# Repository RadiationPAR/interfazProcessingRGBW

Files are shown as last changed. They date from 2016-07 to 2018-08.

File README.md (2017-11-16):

# PowerPAR-Led DELMA
---
La formulación de un problema es a menudo más esencial que su solución, que puede ser meramente una materia de destreza experimental o matemática. "La especificación del problema a investigar implica que se ha comprendido plenamente el
tema de la investigación, hasta el punto de poder determinar exactamente los interrogantes principales que plantea y a cuya resolución se debe orientar la investigación." Einstein

## SISTEMA DE MEDICIÓN Y MONITOREO PARA EL ESTUDIO DEL EFECTO DE LA RADIACIÓN PAR EN LAS PLANTAS

Esta investigación discrimina la información científica y tecnológica experimental a la fecha sobre la Radiación Fotosintéticamente Activa (radiación integrada del rango de longitudes de onda que son capaces de producir actividad fotosintética en las plantas y otros organismos fotosintéticos como microalgas y bacterias).

Investigadores de todo el planeta exponen en sus artículos que los vegetales necesitan porciones de luz desde los 400nm hasta los 700 nm; conocer sus umbrales luminicos permitirá conseguir cosechas de gran producción y alta calidad; llevar un historial de datos sobre el efecto de la longitud de onda según las horas del día y los estadios de crecimiento de la planta permitirá a futuro disponer de hojas de datos para realizar agricultura de precisión en su parametro luminico. 

A continuación se plantea el desarrollo de un mecanismo de observación para la respuesta fisiológica del dosel vegetal (en especial de la fotosíntesis), a partir del diseño de un sistema de iluminación artificial basado en un estudio previo de sistemas de iluminación y la actual migración a sistemas de iluminación con tecnología LED y OLED cuyo espectro de radiación esta dado en una banda especifica lo que proporciona un menor gasto de potencia, y facilita irradiar la planta con la parte del espectro especifico que ella necesita según su estadio: germinación, vegetación y floración. 

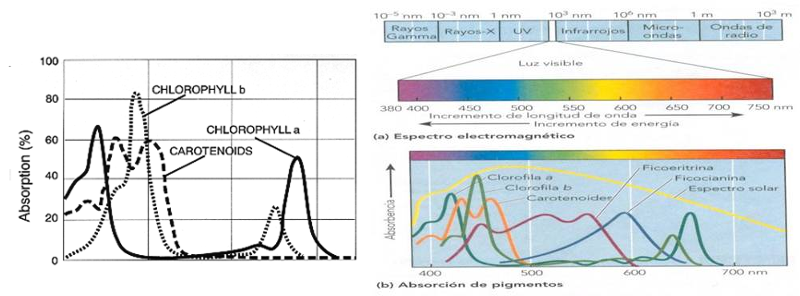
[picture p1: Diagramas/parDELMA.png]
RadiacionPAR
 

Fabricantes de todo el mundo, ofrecen al mercado diversas lamparas de iluminación y en algunos casos se diseñan enormes arreglos de leds con iluminación fija o invariable garantizando solo su uso para determinado tipo de plantas (C3, C4, CAM) - plantas presentes en la industria hortícola de mayor producción. Los investigadores de diversas tesis de Maestría y Doctorado no realizan un proceso fiable para llevar la trazabilidad de sus datos pero nos ilustran sobre el metodo científico iterado para obtener mejoras en el proceso de crecimiento y floración de diversas genéticas de plantas.  

Esta investigación contempla el desarrollo de un prototipo que permite al usuario manejar: la composición de color (longitud de onda) a irradiar y su potencia a traves de una interfaz de fácil manejo que almacena datos de manera centralizada como lo son: composición RGB (0-255), composición CMY (0 - 255), Matiz (0 - 360), saturación (0.0 - 1.0), luminancia (0.0 - 1.0), posición XYZ del color, longitud de onda y frecuencia.   

# Materiales
---  
## Microcontrolador Tiva C Series  
Se decide implementar este microcontrolador por su fama en internet acerca de la adquisición, procesamiento y almacenamiento de datos; ademas se sirve de una librería para la compresión de algoritmos matemáticos, lo cual resulta bastante interesante y acorde para las conversiones de los diferentes modelos matemáticos de los espacios del color.
Energia LaunchPad MSP-EXP430G2 LaunchPad 

## Sensor TCS3220 y Led RGB 100W
Se opta por implementar el sensor TCS3220 por su resolución y economía; basicamente entrega una señal cuadrada con ancho de pulso variable de acuerdo a la presencia de una fuente de luz. Se caracteriza el comportamiento del sensor con la hoja de datos del fabricante y datos de pruebas en el laboratorio de ensayos eléctricos de la Universidad Nacional - LABE.  

Sensor TCS3220
Caracteristicas TCS3220  

El led de 100W permite dimensionar espacios de manera modular y cumple con los requisitos mínimos de lumenes para estimular la fotosíntesis en plantas C3, C4 y CAM.

# Diseño esquematico y PCB 
---  
## Circuito de Potencia
PCB

## Circuito de Control
PCB2  

---  

# Interfaz de Control con Processing desde una Raspberry
Processing Interfaz
Processing Interfaz

Para el desarrollo de la interfaz se usa el software libre Processing - ampliamente usado para comunicación entre el usuario y la maquina por el protocolo RS-232 haciendo el llamado de la libreria "ControlP5".  
Para configurarle en una **raspberry** deben ejecutarse los siguientes comandos: 
<pre><code>cd interfazProcessingRGBW/PROCESSING/controlP5-2.2.5/controlP5/library</code></pre>
<pre><code>cp controlP5.jar /usr/local/lib/processing-3.2.3/core/library</code></pre>  
---

## Investigador principal
* Diego Javier Mena - Email: ingelectronicadj@gmail.com

## Apoyo a la investigación
ApoyoInvest apoyo

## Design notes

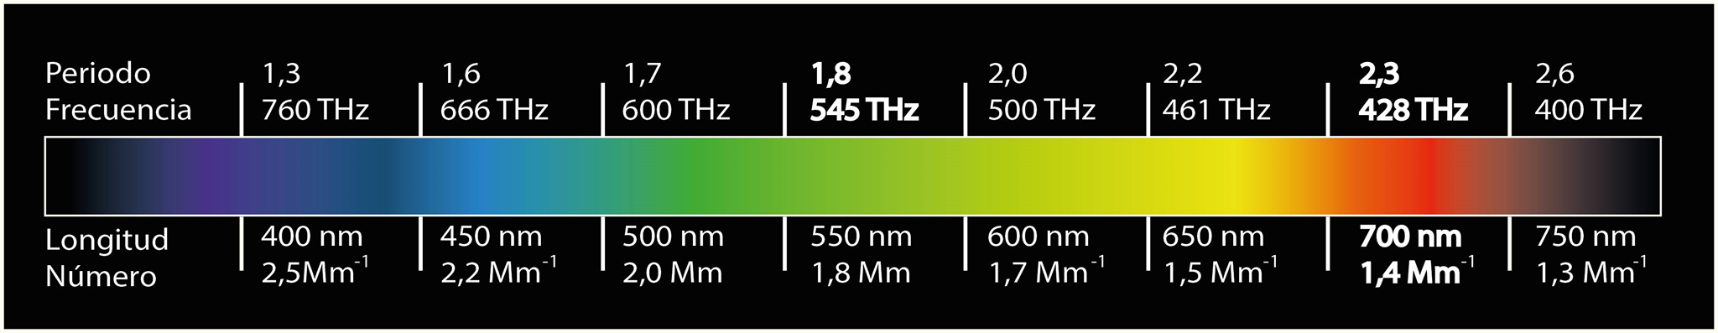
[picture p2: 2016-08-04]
interfaz/ProcessingControlRGBW/imagenes/espectroPAR.png

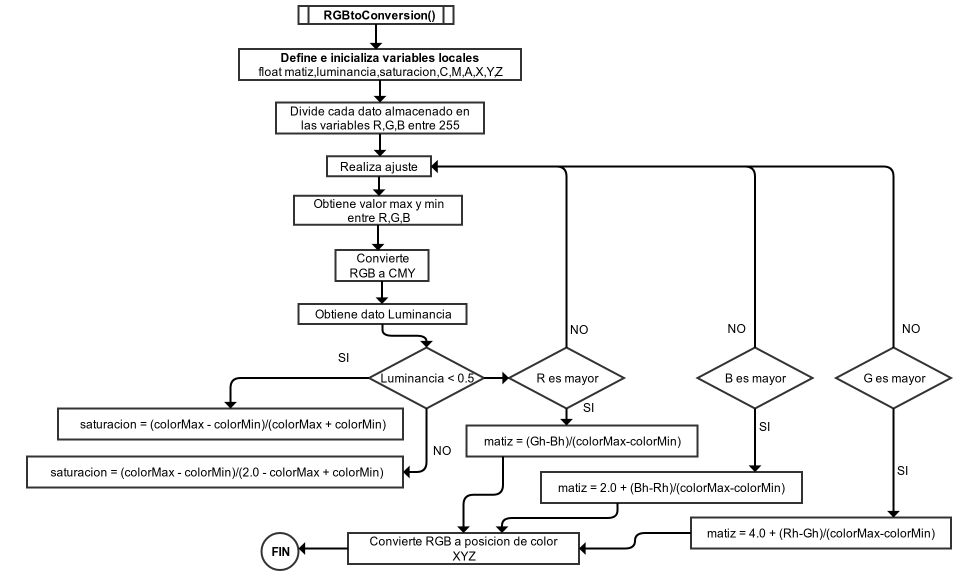
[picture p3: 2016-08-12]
Diagramas/PROCESSING5.png

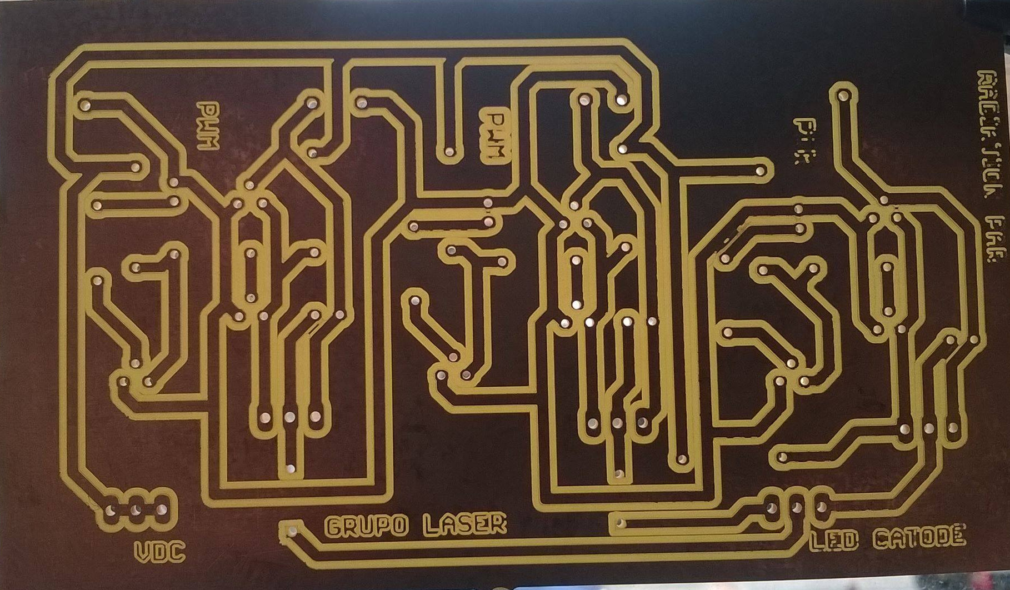
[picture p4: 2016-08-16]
PCB_potencia/pcb.jpg

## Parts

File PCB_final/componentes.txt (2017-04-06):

Partlist exported from /home/asus/ganttproject/interfazProcessingRGBW/PCB_final/untitled.sch at 29/01/17 12:55

Part         Value            Device           Package            Description                                                                                                   MF MPN       OC_FARNELL OC_NEWARK PACKAGE SUPPLIER         
CXTAL1       22p              C-USC0805        C0805              CAPACITOR, American symbol                                                                                                                                               
CXTAL2       22p              C-USC0805        C0805              CAPACITOR, American symbol                                                                                                                                               
C_DEC1       100n             C-USC0805        C0805              CAPACITOR, American symbol                                                                                                                                               
C_DEC2       100n             C-USC0805        C0805              CAPACITOR, American symbol                                                                                                                                               
C_DEC3       100n             C-USC0805        C0805              CAPACITOR, American symbol                                                                                                                                               
C_DEC4       100n             C-USC0805        C0805              CAPACITOR, American symbol                                                                                                                                               
C_DEC5       100n             C-USC0805        C0805              CAPACITOR, American symbol                                                                                                                                               
C_RST        220n             C-USC0805        C0805              CAPACITOR, American symbol                                                                                                                                               
C_TANTALIO   0.1u             C-USC1206        C1206              CAPACITOR, American symbol                                                                                                                                               
C_VCC        100n             C-USC0805        C0805              CAPACITOR, American symbol                                                                                                                                               
C_VDDC1      100n             C-USC0805        C0805              CAPACITOR, American symbol                                                                                                                                               
C_VDDC2      100n             C-USC0805        C0805              CAPACITOR, American symbol                                                                                                                                               
JTAG         M05X2SHD         M05X2SHD         2X5-SHROUDED       Header 5x2                                                                                                                                                               
R_PG/VO      330K             R-US_M1206       M1206              RESISTOR, American symbol                                                                                                                                                
R_RST        10K              R-US_M1206       M1206              RESISTOR, American symbol                                                                                                                                                
SV1                           MA04-1           MA04-1             PIN HEADER                                                                                                                 unknown    unknown                            
SV2                           MA04-1           MA04-1             PIN HEADER                                                                                                                 unknown    unknown                            
SV3                           MA04-1           MA04-1             PIN HEADER                                                                                                                 unknown    unknown                            
SV4                           MA04-1           MA04-1             PIN HEADER                                                                                                                 unknown    unknown                            
TM4C123FH6PM TM4C123[6,F]XXPM TM4C123[6,F]XXPM PM_S-PQFP-G64                                                                                                                                                                               
U1           TPS76633D        TPS76633D        SOIC127P600X175-8N ULTRALOW QUIESCENT CURRENT 250-mA  LOW DROPOUT VOLTAGE REGULATORS                                                TPS76633D 8461422    77C1060   SOIC-8  Texas Instruments
U3                            USB""            USB-MICRO-SMD      This is a USB AB connector that is compatible with USB OTG. i.e. this connector can serve as a host or device                                                            
XTAL         16Mhz            CRYSTALHC49UP    HC49UP             CRYSTAL                                                                                                                    unknown    unknown

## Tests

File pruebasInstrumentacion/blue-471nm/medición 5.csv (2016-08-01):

Number | 1 | 2 | 3 | 4 | 5 | 6 | 7 | 8 | 9
Sequence | 4 | 5 | 6 | 7 | 8 | 9 | 10 | 11 | 12
Time | 8/1/2016 11:17:13 AM | 8/1/2016 11:20:27 AM | 8/1/2016 11:25:31 AM | 8/1/2016 11:26:52 AM | 8/1/2016 11:27:27 AM | 8/1/2016 11:28:14 AM | 8/1/2016 11:30:04 AM | 8/1/2016 11:30:53 AM | 8/1/2016 11:31:05 AM
User
Computer | Labe-PC12 | Labe-PC12 | Labe-PC12 | Labe-PC12 | Labe-PC12 | Labe-PC12 | Labe-PC12 | Labe-PC12 | Labe-PC12
Job
Device
Comment
Sequence Comment
Version | 3.0.14.799 | 3.0.14.799 | 3.0.14.799 | 3.0.14.799 | 3.0.14.799 | 3.0.14.799 | 3.0.14.799 | 3.0.14.799 | 3.0.14.799
Class | SpectrometerMeasurement | SpectrometerMeasurement | SpectrometerMeasurement | SpectrometerMeasurement | SpectrometerMeasurement | SpectrometerMeasurement | SpectrometerMeasurement | SpectrometerMeasurement | SpectrometerMeasurement
Mode | Scan | Scan | Scan | Scan | Scan | Scan | Scan | Scan | Scan
Group
DUT Type
DUT Manufacturer
DUT Model
DUT Serial Number
DUT Lot
Part Number
Description
Bin
Bin Set
DUT Comment
Photopic Power | 123.353712571321 | 93.4549406525173 | 154.326225444168 | 154.80165519112 | 92.8881555235834 | 93.1427922036499 | 19.7247223713135 | 29.5911719853023 | 29.725082121088
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

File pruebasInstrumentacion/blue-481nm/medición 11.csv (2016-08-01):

Number | 1 | 2 | 3 | 4 | 5 | 6 | 7 | 8 | 9 | 10 | 11 | 12 | 13 | 14 | 15 | 16 | 17 | 18 | 19 | 20
Sequence | 4 | 5 | 6 | 7 | 8 | 9 | 10 | 11 | 12 | 13 | 14 | 15 | 16 | 17 | 18 | 19 | 20 | 21 | 22 | 23
Time | 8/1/2016 11:17:13 AM | 8/1/2016 11:20:27 AM | 8/1/2016 11:25:31 AM | 8/1/2016 11:26:52 AM | 8/1/2016 11:27:27 AM | 8/1/2016 11:28:14 AM | 8/1/2016 11:30:04 AM | 8/1/2016 11:30:53 AM | 8/1/2016 11:31:05 AM | 8/1/2016 11:32:49 AM | 8/1/2016 11:33:34 AM | 8/1/2016 11:33:45 AM | 8/1/2016 12:05:11 PM | 8/1/2016 12:06:53 PM | 8/1/2016 12:08:19 PM | 8/1/2016 12:10:39 PM | 8/1/2016 12:11:00 PM | 8/1/2016 12:12:59 PM | 8/1/2016 12:15:01 PM | 8/1/2016 12:16:45 PM
User
Computer | Labe-PC12 | Labe-PC12 | Labe-PC12 | Labe-PC12 | Labe-PC12 | Labe-PC12 | Labe-PC12 | Labe-PC12 | Labe-PC12 | Labe-PC12 | Labe-PC12 | Labe-PC12 | Labe-PC12 | Labe-PC12 | Labe-PC12 | Labe-PC12 | Labe-PC12 | Labe-PC12 | Labe-PC12 | Labe-PC12
Job
Device
Comment
Sequence Comment
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

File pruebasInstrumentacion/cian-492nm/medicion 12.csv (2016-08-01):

Number | 1 | 2 | 3 | 4 | 5 | 6 | 7 | 8 | 9 | 10 | 11 | 12 | 13 | 14 | 15 | 16 | 17 | 18 | 19 | 20 | 21 | 22 | 23 | 24 | 25 | 26 | 27
Sequence | 4 | 5 | 6 | 7 | 8 | 9 | 10 | 11 | 12 | 13 | 14 | 15 | 16 | 17 | 18 | 19 | 20 | 21 | 22 | 23 | 24 | 25 | 26 | 27 | 28 | 29 | 30
Time | 8/1/2016 11:17:13 AM | 8/1/2016 11:20:27 AM | 8/1/2016 11:25:31 AM | 8/1/2016 11:26:52 AM | 8/1/2016 11:27:27 AM | 8/1/2016 11:28:14 AM | 8/1/2016 11:30:04 AM | 8/1/2016 11:30:53 AM | 8/1/2016 11:31:05 AM | 8/1/2016 11:32:49 AM | 8/1/2016 11:33:34 AM | 8/1/2016 11:33:45 AM | 8/1/2016 12:05:11 PM | 8/1/2016 12:06:53 PM | 8/1/2016 12:08:19 PM | 8/1/2016 12:10:39 PM | 8/1/2016 12:11:00 PM | 8/1/2016 12:12:59 PM | 8/1/2016 12:15:01 PM | 8/1/2016 12:16:45 PM | 8/1/2016 12:18:21 PM | 8/1/2016 12:18:34 PM | 8/1/2016 12:19:37 PM | 8/1/2016 12:19:56 PM | 8/1/2016 12:20:10 PM | 8/1/2016 12:21:42 PM | 8/1/2016 12:23:32 PM
User
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

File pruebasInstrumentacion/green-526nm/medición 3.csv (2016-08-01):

Number | 1 | 2 | 3
Sequence | 4 | 5 | 6
Time | 8/1/2016 11:17:13 AM | 8/1/2016 11:20:27 AM | 8/1/2016 11:25:31 AM
User
Computer | Labe-PC12 | Labe-PC12 | Labe-PC12
Job
Device
Comment
Sequence Comment
Version | 3.0.14.799 | 3.0.14.799 | 3.0.14.799
Class | SpectrometerMeasurement | SpectrometerMeasurement | SpectrometerMeasurement
Mode | Scan | Scan | Scan
Group
DUT Type
DUT Manufacturer
DUT Model
DUT Serial Number
DUT Lot
Part Number
Description
Bin
Bin Set
DUT Comment
Photopic Power | 123.353712571321 | 93.4549406525173 | 154.326225444168
Luminous Flux | 0 | 0 | 0
Luminous Efficacy | 0 | 0 | 0
Illuminance | 123.353712571321 | 93.4549406525173 | 154.326225444168
Luminous Intensity | 0 | 0 | 0
Luminance | 0 | 0 | 0
Tristimulus X | 278.731977490448 | 207.905080253394 | 40.8399885888317
Tristimulus Y | 123.353712571321 | 93.4549406525173 | 154.326225444168
Tristimulus Z | 4.89816053845532 | 7.00358397497575 | 29.5794402472916
Cx | 0.684872328667025 | 0.674220553147647 | 0.181716477320172
Cy | 0.303092401306335 | 0.303067350275064 | 0.686670565170084
u' | 0.52008732115655 | 0.509965016255715 | 0.0668283273466551
v' | 0.517874126366776 | 0.515774737729549 | 0.568194769493594
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

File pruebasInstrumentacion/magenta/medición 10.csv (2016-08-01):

Number | 1 | 2 | 3 | 4 | 5 | 6 | 7 | 8 | 9 | 10 | 11 | 12 | 13 | 14 | 15 | 16 | 17 | 18 | 19
Sequence | 4 | 5 | 6 | 7 | 8 | 9 | 10 | 11 | 12 | 13 | 14 | 15 | 16 | 17 | 18 | 19 | 20 | 21 | 22
Time | 8/1/2016 11:17:13 AM | 8/1/2016 11:20:27 AM | 8/1/2016 11:25:31 AM | 8/1/2016 11:26:52 AM | 8/1/2016 11:27:27 AM | 8/1/2016 11:28:14 AM | 8/1/2016 11:30:04 AM | 8/1/2016 11:30:53 AM | 8/1/2016 11:31:05 AM | 8/1/2016 11:32:49 AM | 8/1/2016 11:33:34 AM | 8/1/2016 11:33:45 AM | 8/1/2016 12:05:11 PM | 8/1/2016 12:06:53 PM | 8/1/2016 12:08:19 PM | 8/1/2016 12:10:39 PM | 8/1/2016 12:11:00 PM | 8/1/2016 12:12:59 PM | 8/1/2016 12:15:01 PM
User
Computer | Labe-PC12 | Labe-PC12 | Labe-PC12 | Labe-PC12 | Labe-PC12 | Labe-PC12 | Labe-PC12 | Labe-PC12 | Labe-PC12 | Labe-PC12 | Labe-PC12 | Labe-PC12 | Labe-PC12 | Labe-PC12 | Labe-PC12 | Labe-PC12 | Labe-PC12 | Labe-PC12 | Labe-PC12
Job
Device
Comment
Sequence Comment
Version | 3.0.14.799 | 3.0.14.799 | 3.0.14.799 | 3.0.14.799 | 3.0.14.799 | 3.0.14.799 | 3.0.14.799 | 3.0.14.799 | 3.0.14.799 | 3.0.14.799 | 3.0.14.799 | 3.0.14.799 | 3.0.14.799 | 3.0.14.799 | 3.0.14.799 | 3.0.14.799 | 3.0.14.799 | 3.0.14.799 | 3.0.14.799
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

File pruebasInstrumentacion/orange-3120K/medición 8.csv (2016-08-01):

Number | 1 | 2 | 3 | 4 | 5 | 6 | 7 | 8 | 9 | 10 | 11 | 12 | 13 | 14 | 15 | 16 | 17
Sequence | 4 | 5 | 6 | 7 | 8 | 9 | 10 | 11 | 12 | 13 | 14 | 15 | 16 | 17 | 18 | 19 | 20
Time | 8/1/2016 11:17:13 AM | 8/1/2016 11:20:27 AM | 8/1/2016 11:25:31 AM | 8/1/2016 11:26:52 AM | 8/1/2016 11:27:27 AM | 8/1/2016 11:28:14 AM | 8/1/2016 11:30:04 AM | 8/1/2016 11:30:53 AM | 8/1/2016 11:31:05 AM | 8/1/2016 11:32:49 AM | 8/1/2016 11:33:34 AM | 8/1/2016 11:33:45 AM | 8/1/2016 12:05:11 PM | 8/1/2016 12:06:53 PM | 8/1/2016 12:08:19 PM | 8/1/2016 12:10:39 PM | 8/1/2016 12:11:00 PM
User
Computer | Labe-PC12 | Labe-PC12 | Labe-PC12 | Labe-PC12 | Labe-PC12 | Labe-PC12 | Labe-PC12 | Labe-PC12 | Labe-PC12 | Labe-PC12 | Labe-PC12 | Labe-PC12 | Labe-PC12 | Labe-PC12 | Labe-PC12 | Labe-PC12 | Labe-PC12
Job
Device
Comment
Sequence Comment
Version | 3.0.14.799 | 3.0.14.799 | 3.0.14.799 | 3.0.14.799 | 3.0.14.799 | 3.0.14.799 | 3.0.14.799 | 3.0.14.799 | 3.0.14.799 | 3.0.14.799 | 3.0.14.799 | 3.0.14.799 | 3.0.14.799 | 3.0.14.799 | 3.0.14.799 | 3.0.14.799 | 3.0.14.799
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

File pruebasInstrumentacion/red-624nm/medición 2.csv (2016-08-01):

Number | 1 | 2
Sequence | 4 | 5
Time | 8/1/2016 11:17:13 AM | 8/1/2016 11:20:27 AM
User
Computer | Labe-PC12 | Labe-PC12
Job
Device
Comment
Sequence Comment
Version | 3.0.14.799 | 3.0.14.799
Class | SpectrometerMeasurement | SpectrometerMeasurement
Mode | Scan | Scan
Group
DUT Type
DUT Manufacturer
DUT Model
DUT Serial Number
DUT Lot
Part Number
Description
Bin
Bin Set
DUT Comment
Photopic Power | 123.353712571321 | 93.4549406525173
Luminous Flux | 0 | 0
Luminous Efficacy | 0 | 0
Illuminance | 123.353712571321 | 93.4549406525173
Luminous Intensity | 0 | 0
Luminance | 0 | 0
Tristimulus X | 278.731977490448 | 207.905080253394
Tristimulus Y | 123.353712571321 | 93.4549406525173
Tristimulus Z | 4.89816053845532 | 7.00358397497575
Cx | 0.684872328667025 | 0.674220553147647
Cy | 0.303092401306335 | 0.303067350275064
u' | 0.52008732115655 | 0.509965016255715
v' | 0.517874126366776 | 0.515774737729549
u | 0.52008732115655 | 0.509965016255715
v | 0.345249417577851 | 0.343849825153033
CCT | 0 | 0
Duv | 0 | 0
Du'v' | 0 | 0
CRI Ra | -100 | -100
R1 | -100 | -100
R2 | -100 | -100
R3 | -100 | -100
R4 | -100 | -100
R5 | -100 | -100
R6 | -100 | -100
R7 | -100 | -100
R8 | -100 | -100
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

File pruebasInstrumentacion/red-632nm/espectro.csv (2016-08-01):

Number | 1
Sequence | 4
Time | 8/1/2016 11:17:13 AM
User
Computer | Labe-PC12
Job
Device
Comment
Sequence Comment
Version | 3.0.14.799
Class | SpectrometerMeasurement
Mode | Scan
Group
DUT Type
DUT Manufacturer
DUT Model
DUT Serial Number
DUT Lot
Part Number
Description
Bin
Bin Set
DUT Comment
Photopic Power | 123.353712571321
Luminous Flux | 0
Luminous Efficacy | 0
Illuminance | 123.353712571321
Luminous Intensity | 0
Luminance | 0
Tristimulus X | 278.731977490448
Tristimulus Y | 123.353712571321
Tristimulus Z | 4.89816053845532
Cx | 0.684872328667025
Cy | 0.303092401306335
u' | 0.52008732115655
v' | 0.517874126366776
u | 0.52008732115655
v | 0.345249417577851
CCT | 0
Duv | 0
Du'v' | 0
CRI Ra | -100
R1 | -100
R2 | -100
R3 | -100
R4 | -100
R5 | -100
R6 | -100
R7 | -100
R8 | -100
R9 | -100
R10 | -100
R11 | -100
R12 | -100
R13 | -100
R14 | -100
CQS Qa | 0
Q1 | 0
Q2 | 0
Q3 | 0
Q4 | 0
Q5 | 0
Q6 | 0
Q7 | 0
Q8 | 0
Q9 | 0
Q10 | 0
Q11 | 0
Q12 | 0
Q13 | 0
Q14 | 0
Q15 | 0
Gamut Area | 0.0138811615852558
Dom Wl | 623.4
Comp Wl | 492.8
Color Purity | 96.4301007844772
Radiometric Power | 0.669536136261406
Flux | 0
Irradiance | 0.669536136261406
Radiance | 0
Radiant Intensity | 0
Peak Wl | 632
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

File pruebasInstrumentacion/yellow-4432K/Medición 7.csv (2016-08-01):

Number | 1 | 2 | 3 | 4 | 5 | 6 | 7 | 8 | 9 | 10 | 11 | 12 | 13 | 14 | 15
Sequence | 4 | 5 | 6 | 7 | 8 | 9 | 10 | 11 | 12 | 13 | 14 | 15 | 16 | 17 | 18
Time | 8/1/2016 11:17:13 AM | 8/1/2016 11:20:27 AM | 8/1/2016 11:25:31 AM | 8/1/2016 11:26:52 AM | 8/1/2016 11:27:27 AM | 8/1/2016 11:28:14 AM | 8/1/2016 11:30:04 AM | 8/1/2016 11:30:53 AM | 8/1/2016 11:31:05 AM | 8/1/2016 11:32:49 AM | 8/1/2016 11:33:34 AM | 8/1/2016 11:33:45 AM | 8/1/2016 12:05:11 PM | 8/1/2016 12:06:53 PM | 8/1/2016 12:08:19 PM
User
Computer | Labe-PC12 | Labe-PC12 | Labe-PC12 | Labe-PC12 | Labe-PC12 | Labe-PC12 | Labe-PC12 | Labe-PC12 | Labe-PC12 | Labe-PC12 | Labe-PC12 | Labe-PC12 | Labe-PC12 | Labe-PC12 | Labe-PC12
Job
Device
Comment
Sequence Comment
Version | 3.0.14.799 | 3.0.14.799 | 3.0.14.799 | 3.0.14.799 | 3.0.14.799 | 3.0.14.799 | 3.0.14.799 | 3.0.14.799 | 3.0.14.799 | 3.0.14.799 | 3.0.14.799 | 3.0.14.799 | 3.0.14.799 | 3.0.14.799 | 3.0.14.799
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

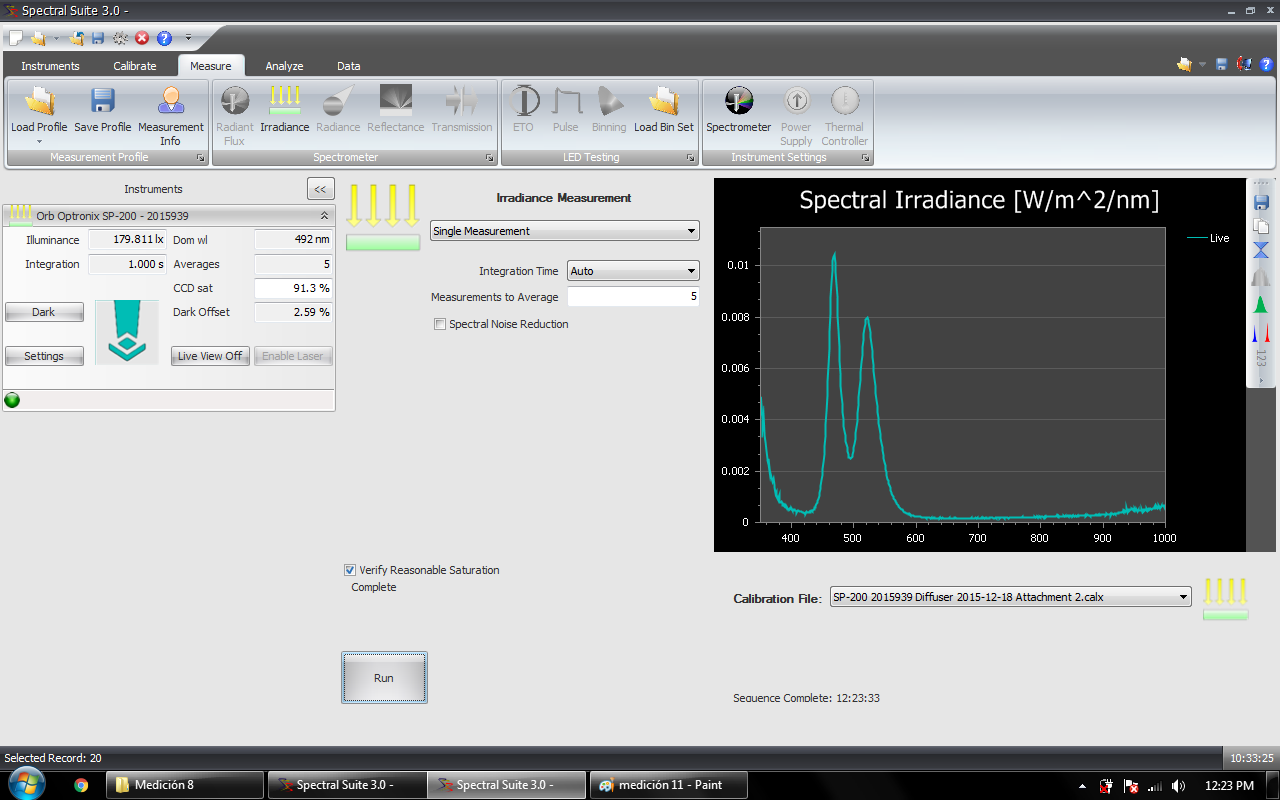
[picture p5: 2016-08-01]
pruebasInstrumentacion/cian-492nm/medición 12.png

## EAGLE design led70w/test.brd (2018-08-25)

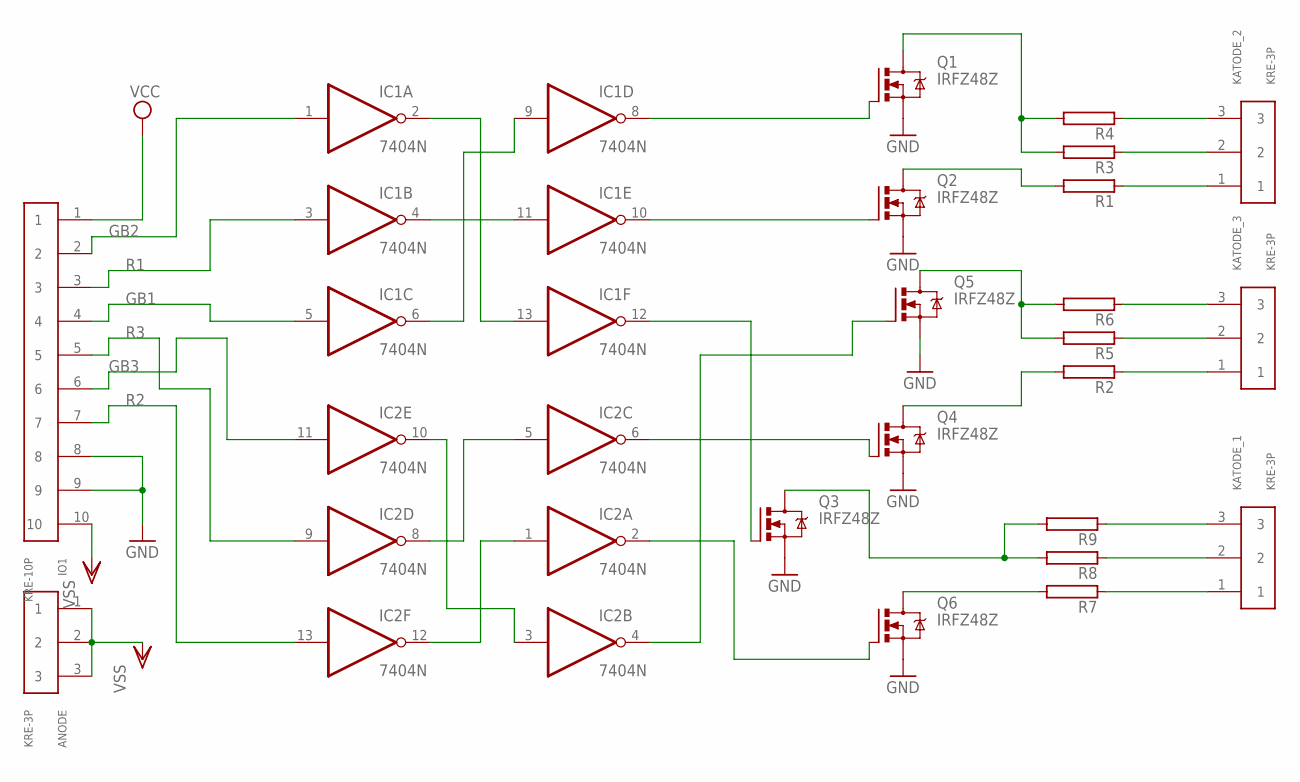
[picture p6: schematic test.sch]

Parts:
ANODE: KRE-3P
IC1, IC2: 7404N; DIL14
IO1: KRE-10P
KATODE_1, KATODE_2, KATODE_3: KRE-3P
Q1, Q2, Q3, Q4, Q5, Q6: IRFZ48Z; TO220BH
R1, R2, R3, R4, R5, R6, R7, R8, R9: RAC10; AC10

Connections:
GB1: IC1.5 (I), IO1.4
GB2: IC1.1 (I), IO1.2
GB3: IC2.11 (I), IO1.6
GND: IC1.7 (GND), IC2.7 (GND), IO1.8, IO1.9, Q1.S, Q2.S, Q3.S, Q4.S, Q5.S, Q6.S
K_B: Q2.D, R1.2
K_B2: Q5.D, R5.2, R6.2
K_R: Q1.D, R3.2, R4.2
unnamed: IC1.8 (O), Q1.G
unnamed: IC1.10 (O), Q2.G
unnamed: KATODE_2.1, R1.1
unnamed: IC1.12 (O), Q3.G
unnamed: IC1.4 (O), IC1.11 (I)
unnamed: IC2.1 (I), IC2.12 (O)
unnamed: IC2.5 (I), IC2.8 (O)
unnamed: IC2.6 (O), Q4.G
unnamed: IC2.2 (O), Q6.G
unnamed: IC2.4 (O), Q5.G
unnamed: IC2.3 (I), IC2.10 (O)
unnamed: IC1.6 (O), IC1.9 (I)
unnamed: KATODE_2.2, R3.1
unnamed: KATODE_2.3, R4.1
unnamed: IC1.2 (O), IC1.13 (I)
unnamed: KATODE_3.1, R2.1
unnamed: KATODE_3.2, R5.1
unnamed: KATODE_3.3, R6.1
unnamed: KATODE_1.1, R7.1
unnamed: KATODE_1.2, R8.1
unnamed: KATODE_1.3, R9.1
unnamed: Q3.D, R8.2, R9.2
unnamed: Q6.D, R7.2
unnamed: Q4.D, R2.2
R1: IC1.3 (I), IO1.3
R2: IC2.13 (I), IO1.7
R3: IC2.9 (I), IO1.5
VCC: IC1.14 (VCC), IC2.14 (VCC), IO1.1
VSS: ANODE.1, ANODE.2, ANODE.3, IO1.10

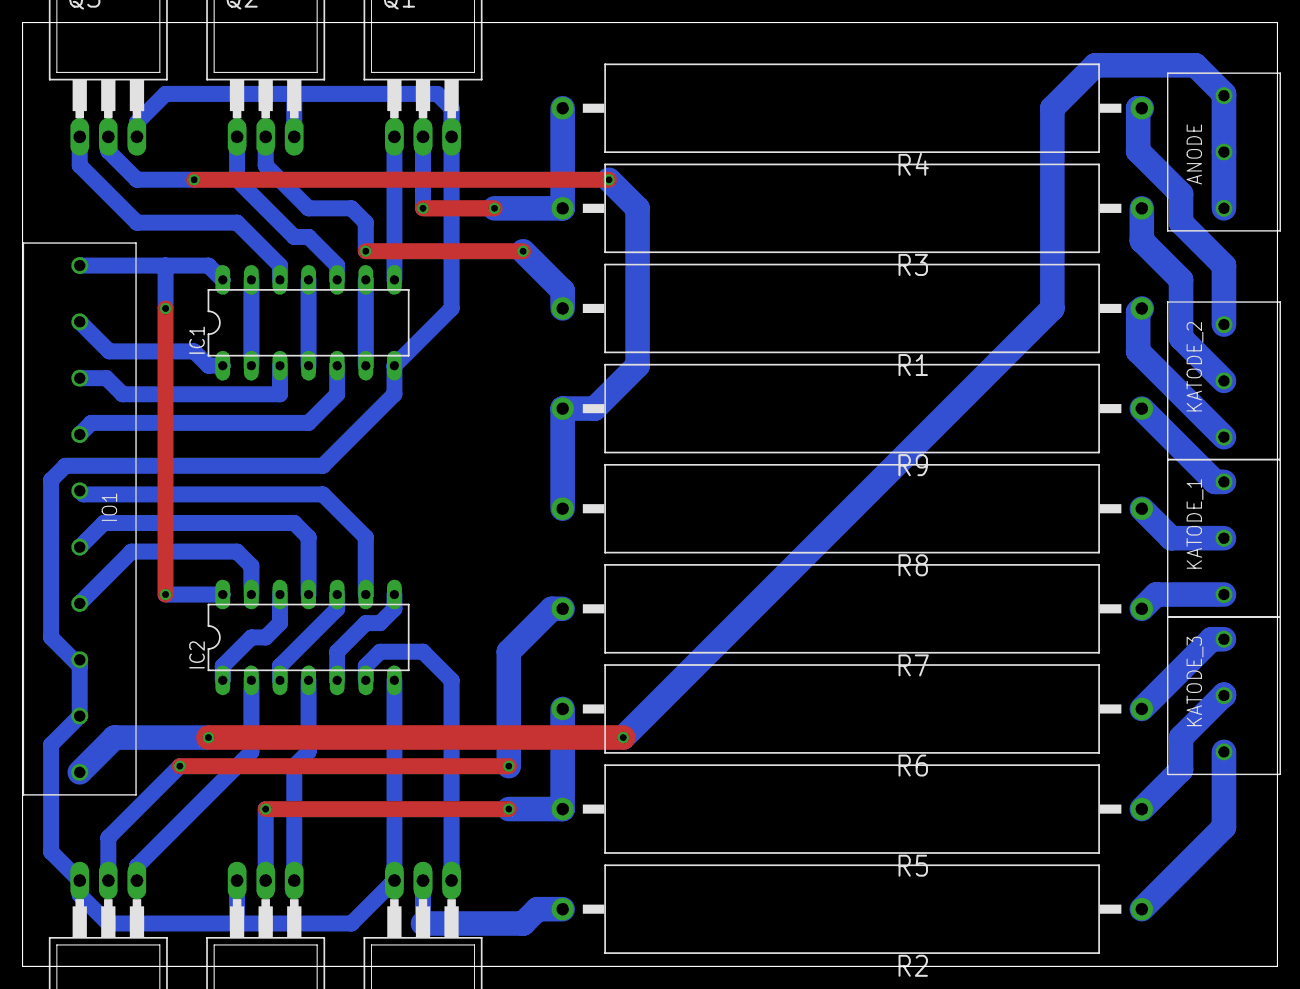
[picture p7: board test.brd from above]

Board: 2 copper layers, 111.4 x 83.8 mm, 22 parts (0 on the bottom side), 36 nets.

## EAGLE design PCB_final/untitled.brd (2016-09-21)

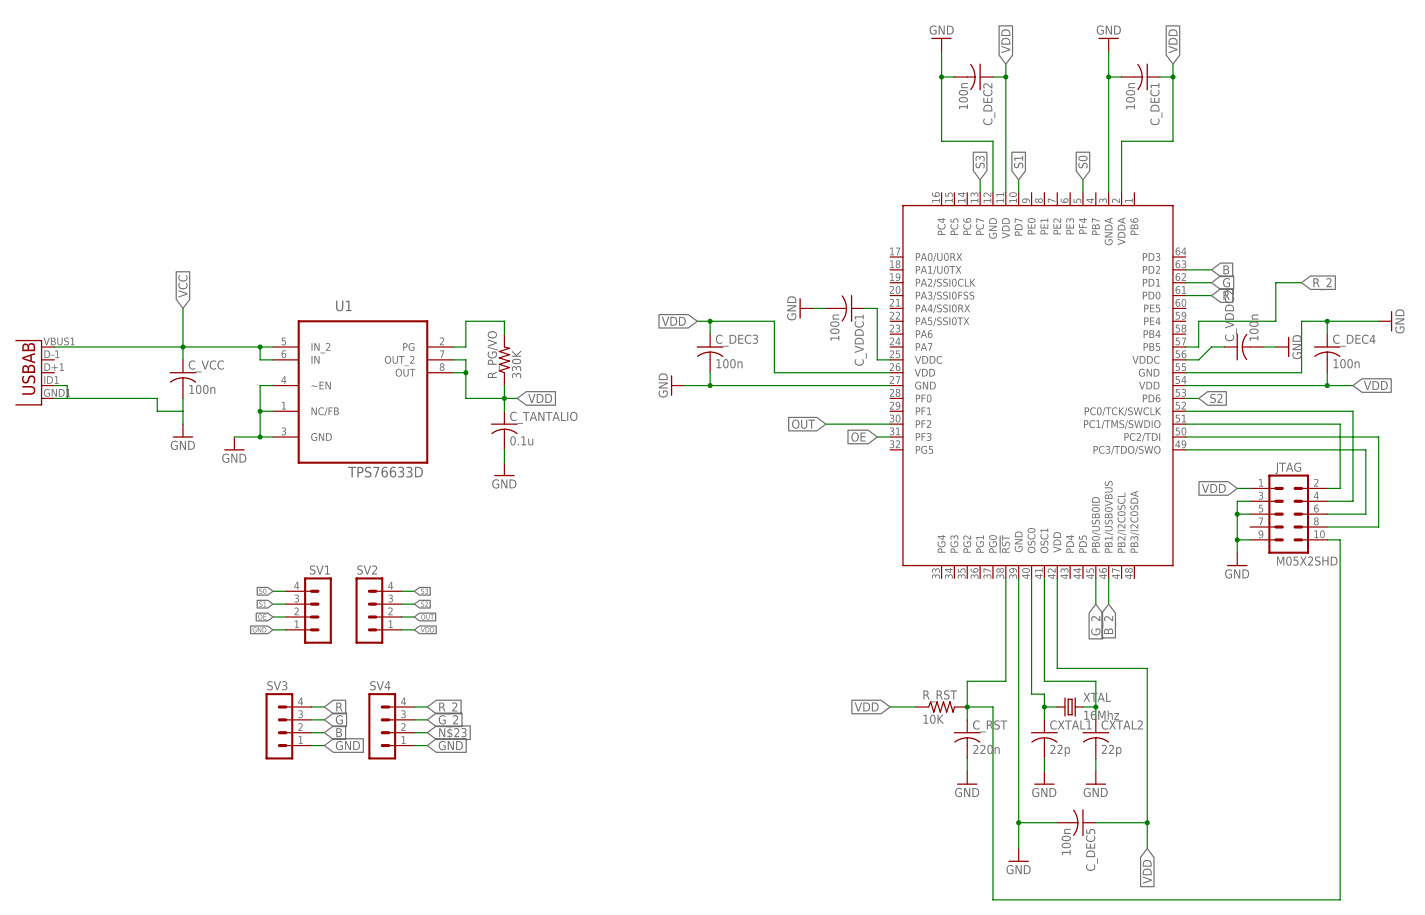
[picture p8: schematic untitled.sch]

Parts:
CXTAL1, CXTAL2: 22p; C0805
C_DEC1, C_DEC2, C_DEC3, C_DEC4, C_DEC5: 100n; C0805
C_RST: 220n; C0805
C_TANTALIO: 0.1u; C1206
C_VCC: 100n; C0805
C_VDDC1, C_VDDC2: 100n; C0805
JTAG: M05X2SHD; 2X5-SHROUDED
R_PG/VO: 330K; M1206
R_RST: 10K; M1206
SV1, SV2, SV3, SV4: MA04-1
TM4C123FH6PM: TM4C123[6,F]XXPM; PM_S-PQFP-G64
U1: TPS76633D; SOIC127P600X175-8N
U3: USB""; USB-MICRO-SMD
XTAL: 16Mhz; HC49UP

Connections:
B: SV3.2, TM4C123FH6PM.63 (PD2)
B_2: TM4C123FH6PM.46 (PB1/USB0VBUS)
G: SV3.3, TM4C123FH6PM.62 (PD1)
GND: CXTAL1.2, CXTAL2.2, C_DEC1.2, C_DEC2.2, C_DEC3.2, C_DEC4.1, C_DEC5.2, C_RST.2, C_TANTALIO.2, C_VCC.2, C_VDDC1.2, C_VDDC2.2, JTAG.3, JTAG.5, JTAG.9, SV1.1, SV3.1, SV4.1, TM4C123FH6PM.3 (GNDA), TM4C123FH6PM.12 (GND), TM4C123FH6PM.27 (GND), TM4C123FH6PM.39 (GND), TM4C123FH6PM.55 (GND), U1.1 (NC/FB), U1.3 (GND), U1.4 (~EN), U3.GND1 (GND), U3.ID1 (USBID)
G_2: SV4.3, TM4C123FH6PM.45 (PB0/USB0ID)
unnamed: CXTAL1.1, TM4C123FH6PM.40 (OSC0), XTAL.1
unnamed: CXTAL2.1, TM4C123FH6PM.41 (OSC1), XTAL.2
unnamed: C_VDDC1.1, TM4C123FH6PM.25 (VDDC)
unnamed: JTAG.2, TM4C123FH6PM.51 (PC1/TMS/SWDIO)
unnamed: JTAG.4, TM4C123FH6PM.52 (PC0/TCK/SWCLK)
unnamed: C_VDDC2.1, TM4C123FH6PM.56 (VDDC)
unnamed: JTAG.6, TM4C123FH6PM.49 (PC3/TDO/SWO)
unnamed: R_PG/VO.2, U1.2 (PG)
unnamed: JTAG.8, TM4C123FH6PM.50 (PC2/TDI)
unnamed: C_RST.1, JTAG.10, R_RST.2, TM4C123FH6PM.38 (!RST)
OE: SV1.2, TM4C123FH6PM.31 (PF3)
OUT: SV2.2, TM4C123FH6PM.30 (PF2)
R: SV3.4, TM4C123FH6PM.61 (PD0)
R_2: SV4.4, TM4C123FH6PM.57 (PB5)
S0: SV1.4, TM4C123FH6PM.5 (PF4)
S1: SV1.3, TM4C123FH6PM.10 (PD7)
S2: SV2.3, TM4C123FH6PM.53 (PD6)
S3: SV2.4, TM4C123FH6PM.13 (PC7)
VCC: C_VCC.1, U1.5 (IN_2), U1.6 (IN), U3.VBUS1 (VBUS)
VDD: C_DEC1.1, C_DEC2.1, C_DEC3.1, C_DEC4.2, C_DEC5.1, C_TANTALIO.1, JTAG.1, R_PG/VO.1, R_RST.1, SV2.1, TM4C123FH6PM.2 (VDDA), TM4C123FH6PM.11 (VDD), TM4C123FH6PM.26 (VDD), TM4C123FH6PM.42 (VDD), TM4C123FH6PM.54 (VDD), U1.7 (OUT_2), U1.8 (OUT)

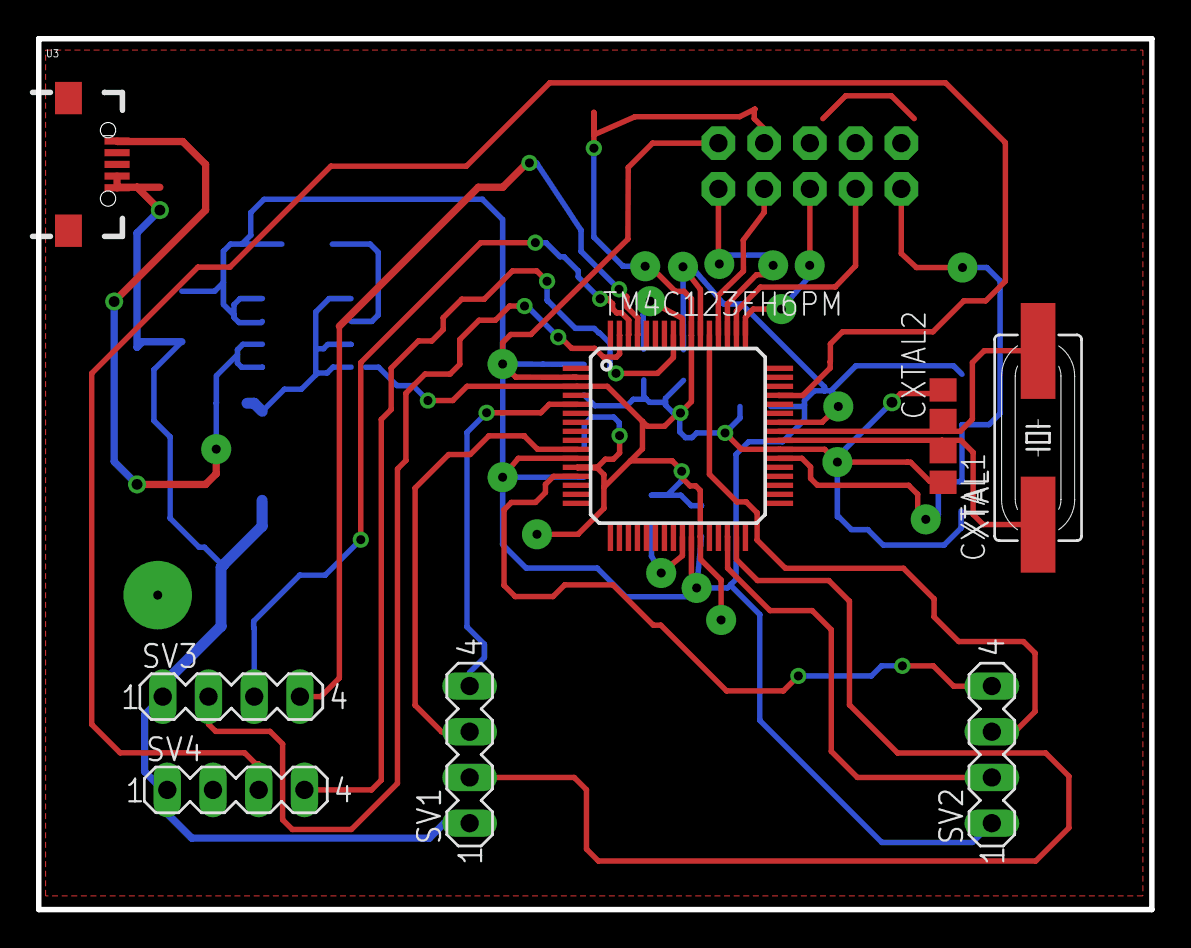
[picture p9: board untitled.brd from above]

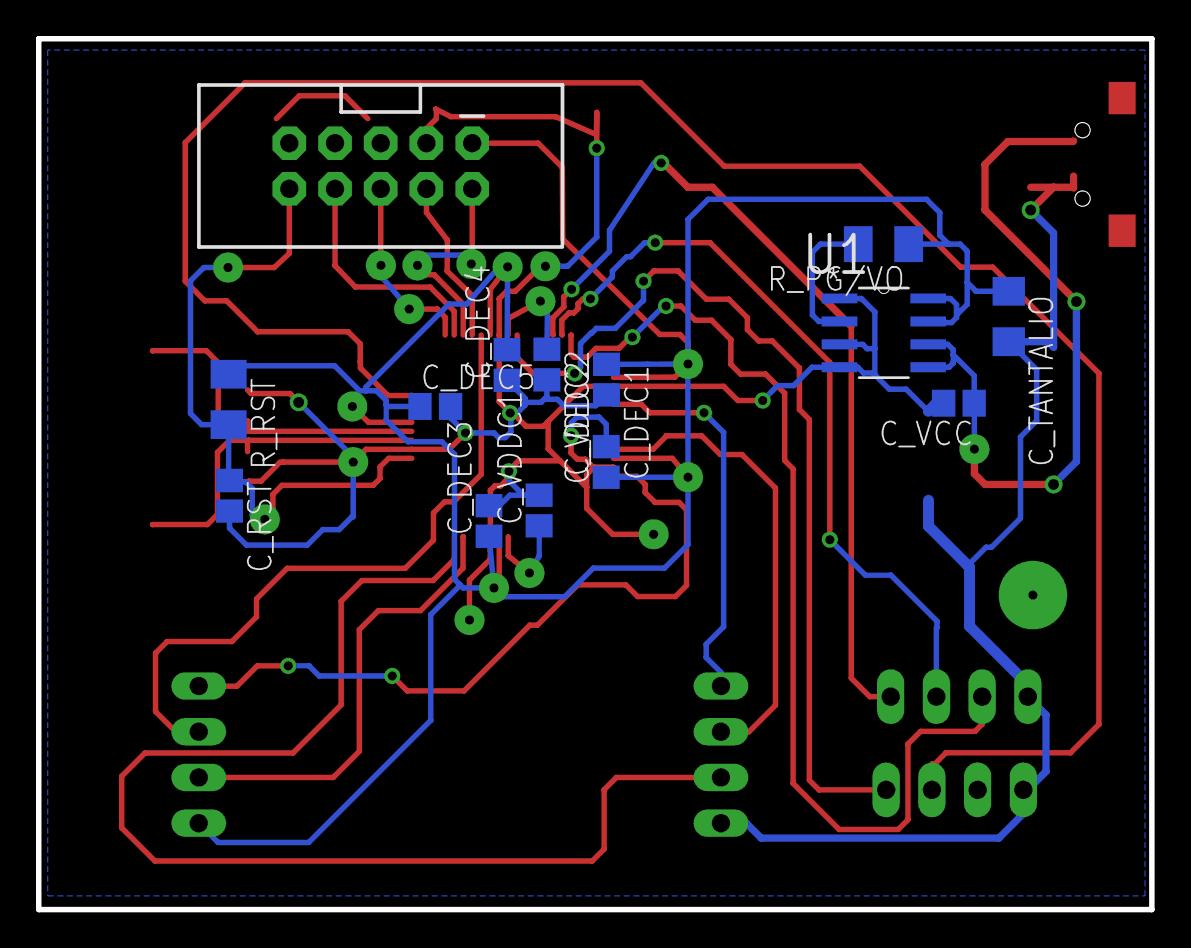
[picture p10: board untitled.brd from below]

Board: 2 copper layers, 61.8 x 48.4 mm, 23 parts (14 on the bottom side), 24 nets.

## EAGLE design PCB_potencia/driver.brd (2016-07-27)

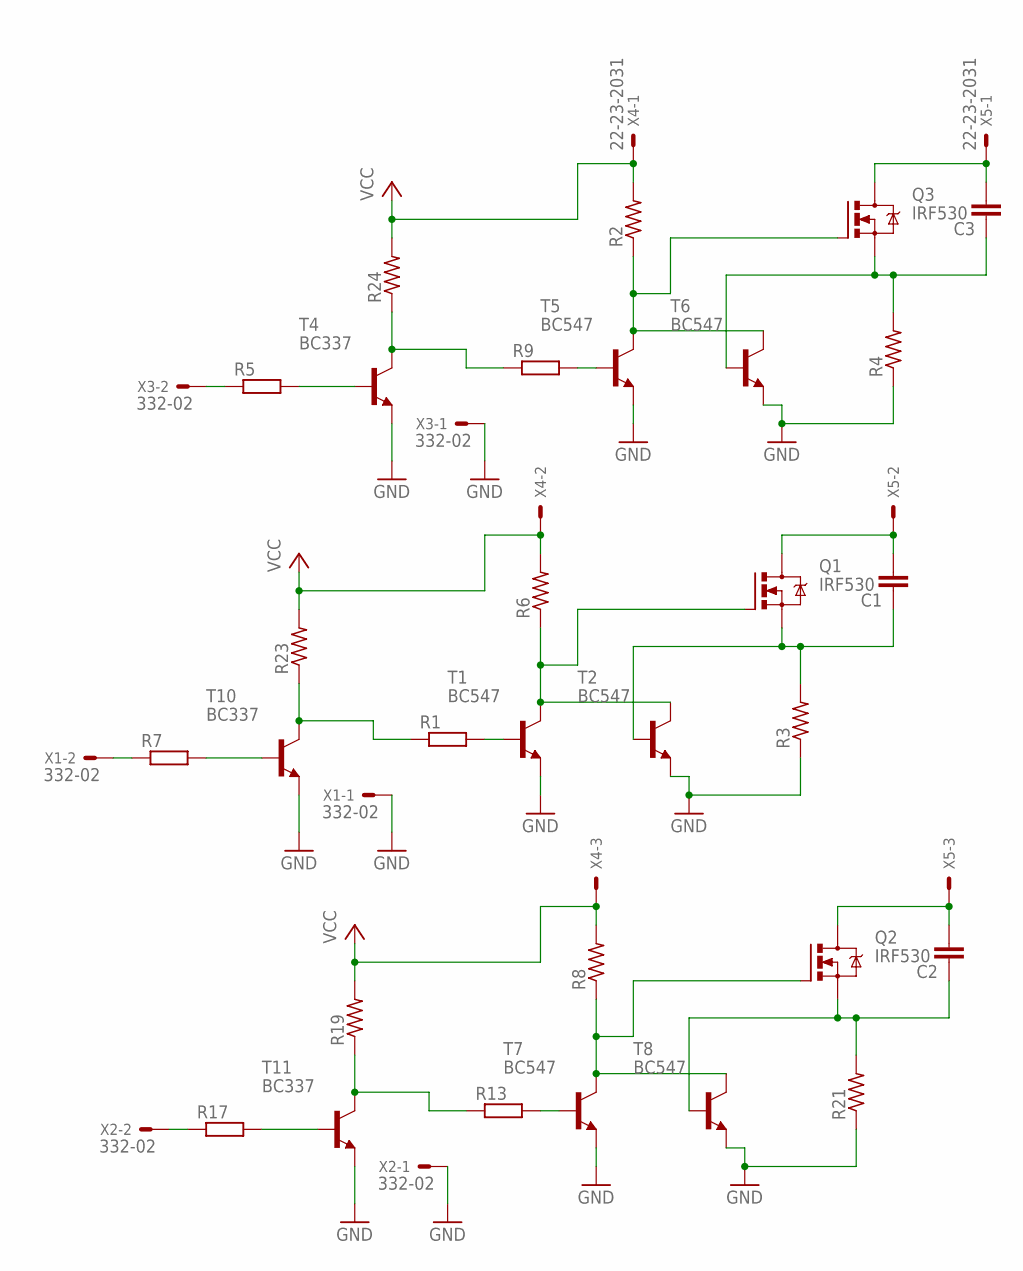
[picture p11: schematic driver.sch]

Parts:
C1, C2, C3: C-EU025-025X050; C025-025X050
Q1, Q2, Q3: IRF530; TO220BV
R1, R9, R13: R0204/7; 0204/7
R2, R6, R8, R19, R23, R24: R-US_0309/10; 0309/10
R3, R4, R21: R-US_0817/22; P0817/22
R5, R7, R17: R-EU_0204/7; 0204/7
T1, T2, T5, T6, T7, T8: BC547; TO92
T4, T10, T11: BC337; TO92
X1, X2, X3: 332-02
X4, X5: 22-23-2031

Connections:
GND: R3.1, R4.1, R21.1, T1.1 (E), T2.1 (E), T4.1 (E), T5.1 (E), T6.1 (E), T7.1 (E), T8.1 (E), T10.1 (E), T11.1 (E), X1.1, X2.1, X3.1
unnamed: R1.2, T1.2 (B)
unnamed: Q1.G, R6.1, T1.3 (C), T2.3 (C)
unnamed: C1.2, Q1.D, X5.2
unnamed: R5.2, T4.2 (B)
unnamed: C1.1, Q1.S, R3.2, T2.2 (B)
unnamed: R7.2, T10.2 (B)
unnamed: R9.1, R24.1, T4.3 (C)
unnamed: R5.1, X3.2
unnamed: R1.1, R23.1, T10.3 (C)
unnamed: R7.1, X1.2
unnamed: R13.2, T7.2 (B)
unnamed: R9.2, T5.2 (B)
unnamed: Q3.G, R2.1, T5.3 (C), T6.3 (C)
unnamed: C3.2, Q3.D, X5.1
unnamed: C3.1, Q3.S, R4.2, T6.2 (B)
unnamed: Q2.G, R8.1, T7.3 (C), T8.3 (C)
unnamed: C2.2, Q2.D, X5.3
unnamed: C2.1, Q2.S, R21.2, T8.2 (B)
unnamed: R17.2, T11.2 (B)
unnamed: R13.1, R19.1, T11.3 (C)
unnamed: R17.1, X2.2
VCC: R2.2, R6.2, R8.2, R19.2, R23.2, R24.2, X4.1, X4.2, X4.3

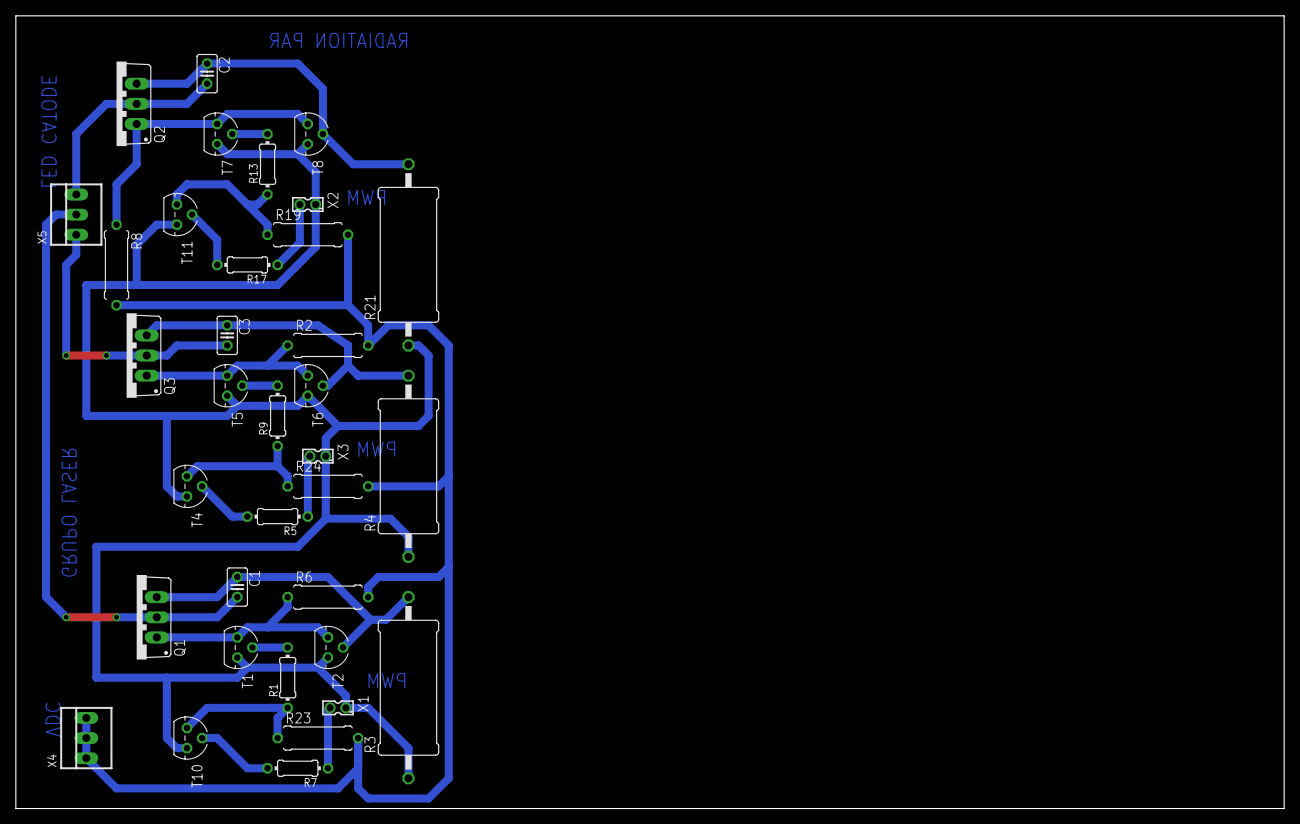
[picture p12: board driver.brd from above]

Board: 2 copper layers, 160.0 x 100.0 mm, 35 parts (0 on the bottom side), 23 nets.

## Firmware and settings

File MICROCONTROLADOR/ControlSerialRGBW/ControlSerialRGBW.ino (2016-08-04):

/*
Sensor LaunchPadComment
VCC 3V3
GND GND
S0  31 Selección para salida de escalado de frecuencia
S1  32 Selección para salida de escalado de frecuencia
S2  33 Selección del tipo de fotodiodo
S3  34 Selección del tipo de fotodiodo
OE  39 habilitación de salida (active low)
OUT 40 Salida-->Onda Cuadrada

 
Opciones seleccionables
------------------
S0 S1 Escalado de frecuencia de salida
L  L  Apagado
L  H  2%
H  L  20% 
H  H  100%

Nota: De acuerdo con la hoja de datos, las salidas a escala reducida se pueden usar cuando
un contador de frecuencia más lenta está disponible. Las funciones PulseIn() maneja un
escalado de frecuencia fijado en un 20%.

s2 S3 Tipo de fotodiodo seleccionado
L  L  Rojo
L  H  Azul
H  L  Sin filtro
H  H  Verde
*/

/*
 ***********************************************************************
 *              LIBRERIAS y CONSTANTES
 ***********************************************************************
 */

/****Pines Lectura RGBW****/
int pinR = 23;
int pinG = 24;
int pinB = 25;
int pinW = 26;
/****-----------------------****/

/****Pines Lectura RGBW****/
int S0 = 31;
int S1 = 32;
int S2 = 33;
int S3 = 34;
int OEPin = 39;
int outPin = 40;
// constantes - ajustables si se presentan lecturas pobres debido a ruido generado por otras fuentes de luz
const int Rc = 100; //Responsividad relativa clara
const int Rr = 99;  // Responsividad relativa roja
const int Rg = 65;  // Responsividad relativa verde 
const int Rb = 70;  // Responsividad relativa azul
/****-----------------------****/

/****Numero de Muestras del Promediador****/
const int nMuestras = 200;
/****-----------------------****/

/*
 ***********************************************************************
 *              SETUP CONFIGURACIÓN INICIAL
 ***********************************************************************
 */
void setup() {
  configurarSerial();
  configurarSalidasPWM();
  configurarPinesSensor();
}

void configurarSerial() {
  Serial.begin(9600);
}

void configurarSalidasPWM() {
  pinMode(pinR, OUTPUT); // rojo
  pinMode(pinG, OUTPUT); // verde
  pinMode(pinB, OUTPUT); // azul
  pinMode(pinW, OUTPUT); // blanco
}

void configurarPinesSensor(){
  pinMode(outPin, INPUT);
  pinMode(OEPin, OUTPUT);
  digitalWrite(OEPin, LOW);// Habilida el escalado de frecuencia
  pinMode(S0, OUTPUT);
  pinMode(S1, OUTPUT);
  digitalWrite(S0, HIGH);// configura el escalado de frecuencia
  digitalWrite(S1, LOW);  
  pinMode(S2, OUTPUT);
  pinMode(S3, OUTPUT);
}


/*
 ***********************************************************************
 *              LOOP BUCLE PRINCIPAL
 ***********************************************************************
 */
void loop() {
  leeSerialRGBW2PC(4,10);//# Canales, # veces que se repite
  serialSensor();
}

void leeSerialRGBW2PC(int canales, int veces){
  for (int i=0; i<veces; i++){
    for (int j=0; j<canales; j++){
      leerBandaRGBW();
    }
  }
}

void leerBandaRGBW() {
  switch(leerPuerto()){
   case 'R':
    analogWrite(pinR, leerPuerto());
    break;
   case 'G':
    analogWrite(pinG, leerPuerto());
    break;
   case 'B':
    analogWrite(pinB, leerPuerto());
    break;
   case 'W':
    analogWrite(pinW, leerPuerto());
    break;
  }
}
// lee el puerto serial
int leerPuerto() {
  while (Serial.available()<=0) {}
  return Serial.read();
}

struct SensorColor {
  int r[nMuestras];
  int g[nMuestras];
  int b[nMuestras];
  int cPulse[nMuestras];
  int rPulse[nMuestras];
  int gPulse[nMuestras];
  int bPulse[nMuestras];
  float promedio(int arreglo[]){
    float suma = 0;
    for (int x = 0; x < nMuestras; x++){
      suma += arreglo[x];
    }
    suma /= nMuestras;
    return suma;
  }
};

struct SensorColor datosSensor;

void serialSensor() {
  for (int i=0; i<nMuestras; i++){
    leerDatosSensor(i);
  }
  enviarDatosSensor();
}

void enviarDatosSensor() {
  struct SensorColor sensor = datosSensor;
  
  Serial.print("cPulse="+String(sensor.promedio(sensor.cPulse))+"&");
  Serial.print("rPulse="+String(sensor.promedio(sensor.rPulse))+"&");
  Serial.print("gPulse= "+String(sensor.promedio(sensor.gPulse))+"&");
  Serial.print("bPulse="+String(sensor.promedio(sensor.bPulse))+"&");
  Serial.print("r="+String(sensor.promedio(sensor.r))+"&");
  Serial.print("g="+String(sensor.promedio(sensor.g))+"&");
  Serial.print("b="+String(sensor.promedio(sensor.b)));
  Serial.println(""); 
}

void leerDatosSensor(int i) {
  int timeout = 1000000;
  
  digitalWrite(S2, HIGH);// Se configura para tomar lectura sin filtro
  digitalWrite(S3, LOW);
  int cPulse = pulseIn(outPin, LOW, timeout);// realiza la lectura
  int Ac = cPulse * Rc;// ajusta la lectura con el valor de responsividad relativa clara
  
  digitalWrite(S2, LOW);// Se configura para tomar lectura filtro rojo
  digitalWrite(S3, LOW);
  int rPulse = pulseIn(outPin, LOW, timeout);// realiza la lectura
  int Ar = rPulse * Rr;// ajusta la lectura con el valor de responsividad relativa roja
  int Cr = Ar - Ac; // aplica correccion para su lectura clara
  
  digitalWrite(S2, HIGH);// Se configura para tomar lectura filtro verde
  digitalWrite(S3, HIGH);
  int gPulse = pulseIn(outPin, LOW, timeout);// realiza lectura

  int Ag = gPulse * Rg;// ajusta la lectura con el valor de responsividad relativa verde  
  int Cg = Ag - Ac;// aplica correccion para su lectura clara
 
  digitalWrite(S2, LOW);// Se configura para tomar lectura filtro azul
  digitalWrite(S3, HIGH);
  int bPulse = pulseIn(outPin, LOW, timeout);// realiza lectura
  int Ab = bPulse * Rb;// ajusta la lectura con el valor de responsividad relativa azul
  int Cb = Ab - Ac;                      // aplica correccion para su lectura clara
  
  //-------------- Encuentra composicion relativa de los colores en pasos de 0 a 255 ----------------
  int r;
  int g;
  int b;
  if (Cr < Cg && Cg < Cb)//  orden del color RGB
  {
    r = 255;
    g = 128 * Cr / Cg;
    b = 16 * Cr / Cb;
  }
  else if (Cr < Cb && Cb < Cg)//  orden del color RGB
  {
    r = 255;
    b = 128 * Cr / Cb;
    g = 16 * Cr / Cg;
  }
  else if (Cg < Cr && Cr < Cb)//  orden del color RGB
  {
    g = 255;
    r = 128 * Cg / Cr;
    b = 16 * Cg / Cb;
  }
  else if (Cg < Cb && Cb < Cr)//  orden del color RGB
  {
    g = 255;
    b = 128 * Cg / Cb;
    r = 16 * Cg / Cr;
  }  
  else if (Cb < Cr && Cr < Cg)//   orden del color RGB
  {
    b = 255;
    r = 128 * Cb / Cr;
    g = 16 * Cb / Cg;
  }  
  else // (Cb < Cg && Cg < Cr)    //   orden del color RGB
  {
    b = 255;
    g = 128 * Cb / Cg;
    r = 32 * Cb / Cr;
  }
  
  
  datosSensor.r[i] = r;
  datosSensor.g[i] = g;
  datosSensor.b[i] = b;
  datosSensor.cPulse[i] = cPulse;
  datosSensor.rPulse[i] = rPulse;
  datosSensor.gPulse[i] = gPulse;
  datosSensor.bPulse[i] = bPulse;
}

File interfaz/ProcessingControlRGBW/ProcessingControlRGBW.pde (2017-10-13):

/*
 ***********************************************************************
 *              LIBRERIAS y CONSTANTES
 ***********************************************************************
 */
 
import controlP5.*;//Graficos interactivos
import processing.serial.*;//Lectura y escritura serial
import java.util.Map;//para crear diccionarios

/*Variables previstas para graficos interactivos*/
ControlP5 interfaz;
Slider2D sliderOnda;
sliderV sliderV1, sliderV2, sliderV3, sliderV4;

/*Definicion de variables para escribir datos PWM al TIVA*/
Serial puertoSerial;
int LINE_FEED = 10;// <LF> constant
int R = 0; //Tono rojo
int G = 0; //Tono verde
int B = 0; //Tono azul
int W = 0; //Brillo
float C,M,A;
float saturacion = 0.0;
float matiz = 0.0;
float anguloMatiz= 0.0;
float luminancia = 0.0;
float X,Y,Z;

/* Tipo de datos para almacenar imágenes .gif, .jpg, .tga, .png */
PImage img, img2, img3;

/*
 ***********************************************************************
 *              SETUP CONFIGURACIÓN INICIAL
 ***********************************************************************
 */
void setup() {
  size(1350, 800); //Define un tamaño para la interfaz
  img = loadImage("imagenes/tux.png");
  img2 = loadImage("imagenes/cromatico.png");
  img3 = loadImage("imagenes/espectrovisible.png");

  // Comprueba disponibilidad de puerto serial en la maquina  
  println("Puerto Serial disponible.");
  println("Dispositivo: "+Serial.list()[0]);
  puertoSerial = new Serial(this, Serial.list()[0], 9600);//9600 es el baudrate o tasa de baudios
  // Setup the serialEvent to be called when we receive complete response
  // packets from the HRMI device
  puertoSerial.bufferUntil(LINE_FEED);//caracter en ascii breakline o salto de linea
 
 
  // Creamos 4 Sliders
  // sliderVx = new sliderV(ubicacion x, ubicacion y, ancho, largo, color);
  sliderV1 = new sliderV(50, 200, 90, 255, #FF0000); 
  sliderV2 = new sliderV(150, 100, 90, 255, #03FF00);
  sliderV3 = new sliderV(250, 100, 90, 255, #009BFF);
  sliderV4 = new sliderV(350, 200, 90, 255, #FFFFFF);

  //Graficamos puntero pantalla azul
  interfaz = new ControlP5(this);//this es el contexto actual (programa)
  sliderOnda = interfaz.addSlider2D("onda")
    .setPosition(600, 240)//x,y
    .setSize(200, 200)//ancho,largo
    .setMinMax(0, 0, 500, 100) //Define valores minimos y maximos de amplitud y frecuencia
    .setValue(150, 50); // Asigna unos valores iniciales para amplitud y frecuencia
  //.disableCrosshair();
  smooth();//Dibuja todas las geometrias en el lienzo de la interfaz grafica
  //frameRate(24); //(fps) Veces por segundo, tasa de refresco de la pantalla/lienzo
}

/****** INICIO FUNCIONES ADICIONALES SETUP******/
/* Funcion para incrustar imagenes, dibujar sliders y visualizador de onda.*/
/* Esta función es un bucle que dibuja en el lienzo, por eso se llama draw.*/
/* Se ejecuta el numero de veces de la tasa de refresco frame rate*/
void draw() {
  dibujarImagenes();
  renderizarSliders();  
  graficarVisualizadorOnda();
  rxtxSerial();
  RGBtoConvert();
  refrezcaTextos();
}

/* Clase Slider */
class sliderV {
  //atributos del objeto
  int x, y, w, h, p;//h=alto,p=rango de 0 a 255 (altura)
  color col;
  boolean slide;
  String texto;
  //constructor del objeto
  public sliderV (int _x, int _y, int _w, int _h, color _col) {
    x = _x;//Posicion X
    y = _y;//Posicion y
    w = _w;//Ancho
    h = _h;//Alto
    p = 60;//Valor (0-255) del PWM inicial (porcentaje)
    col = _col;//Color
    slide = true;
    texto = "";
  }
  //Función que renderiza el objeto
  private void render() {
    noStroke();//Sin contorno, linea de afuera del rectángulo
    fill(col);//color de relleno
    rect(x-1, y-4, w, h+10);
    fill(100,100,100,100);//Rojo,Verde,Azul,Alfa
    rect(x, h-p+y-5, w-2, 13);
    this.escribirEtiquetas();
    this.mouseOver();
  }
  private void escribirEtiquetas() {
    fill(255);
    textSize(11);
    int porcentaje = p * 100 / 255;//Porcentaje
    texto = str(porcentaje) + " %";//Texto porcentaje barras color(sliders)
    text(texto, x+2, h-p+y+6);
  }
  private void mouseOver() {
    if (slide==true && mousePressed==true && mouseX < x+w && mouseX > x) {
      if ((mouseY<=y+h+150) && (mouseY>=y-150)) {
        p = h-(mouseY-y);
        if (p<0) {
          p=0;
        } else if (p>h) {
          p=h;
        }
      }
    }
  }
}

void dibujarImagenes() {
  background(0); //Color de fondo 0=negro
  image(img, 1200, 500);// img ,posicion x, posicion y
  image(img2, 100, 400);
  image(img3, 550, 80);
}

void renderizarSliders() {
  sliderV1.render();//Renderiza slider
  sliderV2.render();
  sliderV3.render();
  sliderV4.render();
}

void graficarVisualizadorOnda() {
  pushMatrix();
  translate(820, 340);//Define posicion
  noStroke();//Deshabilita el trazo (contorno). Si se usa junto con noFill nada es dibujado en pantalla
  fill(50);//Color de llenado
  rect(0, -100, 500, 200);
  strokeWeight(1);//Ancho del trazo (líneas en los objetos)
  line(0, 0, 200, 0);
  stroke(color(R,G,B));//Color del trazo RGB
  strokeWeight(2);
  for (int i=1; i<500; i++) {//Define tamaño max de la onda comprendida entre -PI,PI
    float y0 = cos(map(i-1, 0, sliderOnda.getArrayValue()[0], -PI, PI)) * sliderOnda.getArrayValue()[1]; 
    float y1 = cos(map(i, 0, sliderOnda.getArrayValue()[0], -PI, PI)) * sliderOnda.getArrayValue()[1];
    line((i-1), y0, i, y1);
  }
  popMatrix();//https://processing.org/reference/popMatrix_.html
}
  
void refrezcaTextos() {
  textSize(16);//Tamaño
  fill(255);//Color del texto
  text("LECTURA DE DATOS", 490, 480);
  text("Control rojo   =" + sliderV1.texto, 490, 500);
  text("Control verde =" + sliderV2.texto, 490, 520);
  text("Control azul   =" + sliderV3.texto, 490, 540);
  text("Control brillo =" + sliderV4.texto, 490, 560);
  text("SENSADO", 490, 600);
  text("R =" + R, 490, 620);
  text("G =" + G, 490, 640);
  text("B =" + B, 490, 660);
  text("C =" + C + " %", 620, 620);
  text("M =" + M + " %", 620, 640);
  text("Y =" + A + " %", 620, 660);
  text("Matiz =" + anguloMatiz + " °",800,620);
  text("Saturacion =" + saturacion + " %",800,640);
  text("Luminancia =" + luminancia + " %",800,660);
  text("Posicion X =" + X,1040,620);
  text("Posicion Y =" + Y,1040,640);
  text("Posicion Z =" + Z,1040,660);
  textSize(25);//Tamaño
  text("COMBINATORIAS RGBW", 100, 70); 
  text("ESPECTRO VISIBLE",800,90);
  textSize(16);
  String creditos = "Este obra está bajo una licencia MIT Copyright (c) 2016 RadiationPAR";
  fill(255);
  text(creditos, 920, 520, 300, 400);
}

float tiempoRefrescoDato = 100;//mS
int FPS = 24;//tiempoFPS=1/fps;
int bucles = (int)Math.ceil(tiempoRefrescoDato/1000*FPS);//redondeo hacia arriba
int contadorBucles = 1;//Se inicia el contador en 1 vez
void rxtxSerial(){
  //Se envian y reciben los datos a cierta velocidad
  if(contadorBucles>=bucles){
    escribePWMSerial();
    contadorBucles = 0;
  } else {
    contadorBucles++;
  }
}
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

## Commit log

2016-05-07 Se añade el fichero multimedia de imagenes, recurso para interfaz processing
2016-05-07 Se añade codigo fuente y librerias para interfaz RGBW ejecutable por processing
2016-05-07 Se añade codigo fuente para micro Tiva, generador de 4 PWM y comunicación por puerto serial a processing
2016-05-07 Se añade codigo fuente para lectura del sensor de color TCS3220 empleando el micro Tiva
2016-05-31 Se añade paleta de colores usando D3 para pruebas del TCS3220
2016-07-03 Se unen los fragmentos de codigo del sensor y el control RGBW
2016-07-11 Se añade diseño PCB de potencia para un arreglo (canal) matricial de leds
    [driver2.GBL, driver2.GBO, driver2.GBP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]
2016-07-13 Se añaden funciones de teclado y lectura de puerto serial RS-232
2016-07-16 Se añade diseño PCB driver de potencia RGB
    [driver.brd, driver.sch]
2016-07-17 Se modifica por software la potencia del canal R
2016-07-27 Se corrige transistor para invertir la señal de cada PWM y se ajustan resistencias de potencia
    [driver.brd, driver.sch]
2016-07-31 Se mejora funcion de lectura de caracteres ascii enviados por puerto serial desde la interfaz al micro y se añade funcion de escritura por puerto serial
2016-07-31 Se ordena y se añaden comentarios al codigo fuente de la interfaz en Processing
2016-08-01 Se modifica nombre del fichero por inconsistencias a la hora de lanzar la interfaz
2016-08-01 Se añaden ficheros de pruebas de calibracion con Módulo de Iluminación en Laboratorio de Ensayos Eléctricos Industriales de la Universidad Nacional
    [Medición 6.csv, Medición 4.csv, Medición 7.csv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]
2016-08-01 Se añade función tipo struct para la creación de un objeto
2016-08-01 Se modifica la clase SliderV, se normalizan datos enviados a porcentaje, se modifica fichero de imagenes
2016-08-02 Indentaciones y función promediador de variables en struct
2016-08-02 se corrige promediador y se imprime caracteres en estándar rfc2616
    [ControlSerialRGBW.ino]
2016-08-02 Se ordena el código por funciones y fix imagen croma
    [ProcessingControlRGBW.pde]
2016-08-02 Se pone color capturado como fondo de Grilla
2016-08-04 Se añade funcion para evento Serial, se corrige escritura de datos PWM
    [ProcessingControlRGBW.pde]
2016-08-04 Se leen los 4 Canales N veces antes de RGB/timeout a pulseIn
2016-08-04 Se añade recta angular para representar un dato RGB en Matiz (angulo) útil para la interfaz del croma
2016-08-04 Se cambia imagen del espectro visible, se añaden funciones para obtener la matiz de un color RGB y representarla con un trazo angular sobre la imagen croma
2016-08-07 Se añaden calculos para obtener iluminancia y saturacion del color
2016-08-08 Se añaden lineas de codigo para obtener la posicion de un color RGB a XYZ
2016-08-08 Se añaden lineas de codigo para obtener la representacion CMY (Cian, Magent,Yellow) de un color RGB
2016-08-12 Se añaden diagramas de bloques para la comprension de codigos fuente del microcontrolador como de la interfaz
2016-08-16 Se añade funcion para conversiones de RGB-HSL, RGB-CMY, RGB-XYZ y se pinta un trazo angular para representar la matiz sobre la imagen croma
2016-08-16 Se añaden labels de texto para mostrar en interfaz las conversiones de RGB
2016-08-16 Se pinta onda senoidal del color capturado por el sensor, se rota 90 grados la imagen croma para usar como referencia el 0 grados geometrico y se añade una fotografia del PCB
2016-08-16 Se expresan en porcentajes algunos valores necesarios como C,M,Y,saturacion,luminancia y se deja en grados la matiz
2016-09-14 Se cargan archivos de diseño PCB con el empaquetado del microcontrolador
    [OBC_QB50.brd, OBC_QB50.sch]
2016-09-14 Se elimina ficheros PCB y visorWEB
    [driver2.GBL, driver2.GBO, driver2.GBP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]
2016-09-21 Se añade PCB final
    [untitled.brd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]
2016-12-02 Instrucciones raspberry en el readme
2016-12-08 Se deja por definicion la licencia GPL 3.0 para llevar el proyecto al open hardware design
2016-12-09 se añade funcion para el manejo de fecha y hora
2016-12-13 Queda lista la visualizacion de fecha y hora sobre la interfaz obteniendo el año,mes,dia,hora,min,seg desde el timmer de la raspberry
2017-04-06 Se añade lista de componentes para circuito de control
2017-08-20 Se ajusta el codigo para trabajar el microcontrolador Tiva C Series TM4C123G usando Atom/platformio y se eliminan archivos de poco interes
    [OBC_QB50.brd, OBC_QB50.sch]
2017-10-13 Se añade simulacion base del circuito de potencia, se actualizan codigos de interfaz y microcontrolador
    [disparoMosfet.sch]
2017-10-13 se cargan pruebas de medicion realizadas en el laboratorio de la Universidad Nacional
    [Medición 6.csv, Medición 4.csv, Medición 7.csv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]
2018-08-25 se carga diseño pcb alternativo
    [test.brd, test.sch]

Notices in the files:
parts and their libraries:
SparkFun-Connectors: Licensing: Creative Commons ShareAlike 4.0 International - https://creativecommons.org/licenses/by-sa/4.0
